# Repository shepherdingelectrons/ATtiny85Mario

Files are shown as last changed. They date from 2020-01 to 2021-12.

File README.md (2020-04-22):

# ATtiny85Mario

ATtiny85 Mario

Read about the software and hardware of ATtiny85Mario here:
https://shepherdingelectrons.blogspot.com/2020/01/tinymario.html

and the construction of a handset to play ATtiny85Mario in:

https://shepherdingelectrons.blogspot.com/2020/03/attiny-mario-handset.html

mario animation

Mario-style game with sound effects and music on twin OLED displays driven by ATtiny85 AVR. Having fun with the multiple challenges of working with small system constraints! :-)

**TinyMario**
Source code for Mario.  For music and sound effects to work, the EEPROM must be correctly burned first (see BurnEEPROM_ATtiny85 sketch)

- OLED code is derived from bitbang2's super fast code:
https://github.com/bitbank2/oled_turbo
- Mario theme music is taken from Mike Marburg's transcription of the score:
https://github.com/mikemalburg/arduino_annoyotrons_piezo/tree/master/annoy_piezo_mario_overworld
- Mario animation pixel art:
https://www.hackster.io/138689/pixel-art-on-oled-display-7f8697

**BurnEEPROM_ATtiny85**

Arduino sketch to compress the music and sound effects, then burn to ATTiny85 EEPROM

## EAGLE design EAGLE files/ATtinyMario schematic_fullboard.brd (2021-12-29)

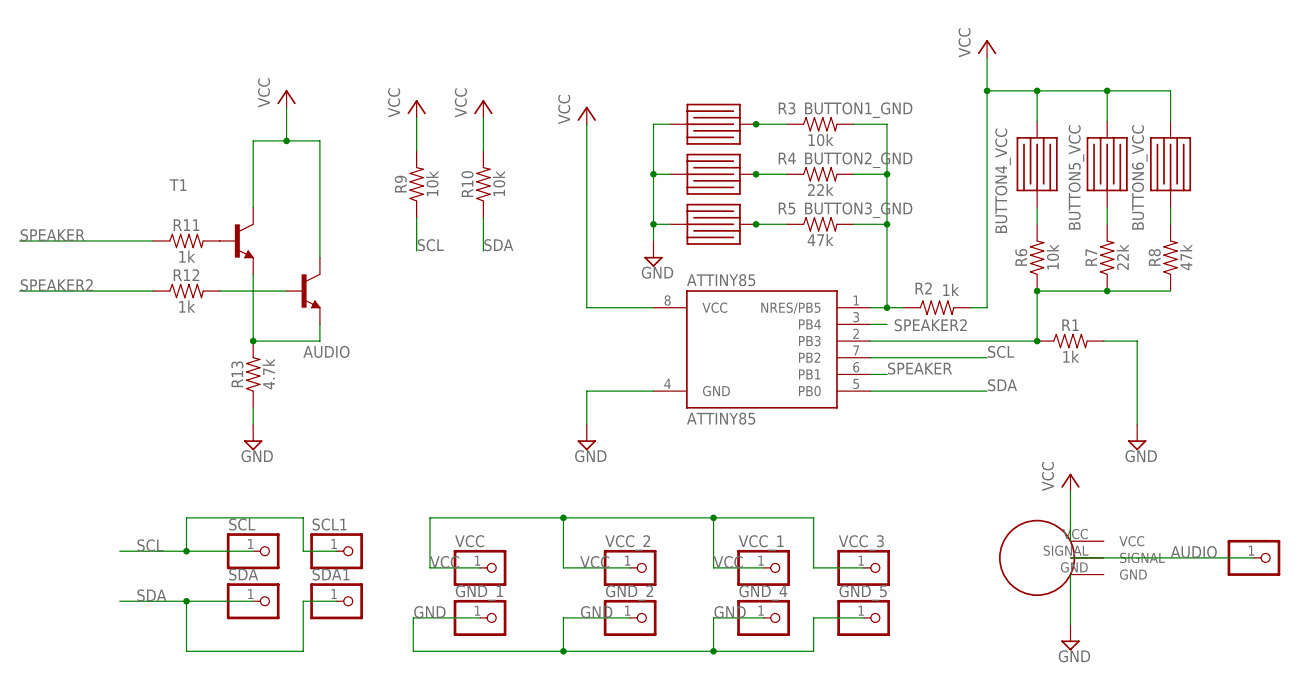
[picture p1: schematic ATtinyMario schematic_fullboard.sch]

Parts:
ATTINY85: ATTINY85; PDIP08_300MIL
GND_1, GND_2, GND_3, GND_4, GND_5: PINHD-1X1; 1X01
R1, R2, R11, R12: 1k; AXIAL-0.3
R3, R6, R9, R10: 10k; AXIAL-0.3
R4, R7: 22k; AXIAL-0.3
R5, R8: 47k; AXIAL-0.3
R13: 4.7k; AXIAL-0.3
SCL, SCL1: PINHD-1X1CB; 1X01-CLEANBIG
SDA, SDA1: PINHD-1X1CB; 1X01-CLEANBIG
T1, T2: 2N2222; TO92-EBC-OVAL
U$1, U$2, U$3, U$4, U$6, U$7: PCB_BUTTON_DEVICE; PCB_BUTTON
U$5: VOLUME_WHEEL; VOLUME_PCB
VCC: PINHD-1X1; 1X01
VCC_1, VCC_2, VCC_3: PINHD-1X1; 1X01

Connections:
AUDIO: GND_3.1, R13.P$2 (2), T1.E, T2.E, U$5.SIGNAL
BUTTON1_GND: R3.P$1 (1), U$1.PAD1
BUTTON2_GND: R4.P$1 (1), U$6.PAD1
BUTTON3_GND: R5.P$1 (1), U$7.PAD1
BUTTON4_VCC: R6.P$2 (2), U$2.PAD2
BUTTON5_VCC: R7.P$2 (2), U$3.PAD2
BUTTON6_VCC: R8.P$2 (2), U$4.PAD2
GND: ATTINY85.4 (GND), GND_1.1, GND_2.1, GND_4.1, GND_5.1, R1.P$2 (2), R13.P$1 (1), U$1.PAD2, U$5.GND, U$6.PAD2, U$7.PAD2
unnamed: ATTINY85.1 (NRES/PB5), R2.P$1 (1), R3.P$2 (2), R4.P$2 (2), R5.P$2 (2)
unnamed: ATTINY85.2 (PB3), R1.P$1 (1), R6.P$1 (1), R7.P$1 (1), R8.P$1 (1)
unnamed: R11.P$2 (2), T1.B
unnamed: R12.P$2 (2), T2.B
SCL: ATTINY85.7 (PB2), R9.P$1 (1), SCL.1, SCL1.1
SDA: ATTINY85.5 (PB0), R10.P$1 (1), SDA.1, SDA1.1
SPEAKER: ATTINY85.6 (PB1), R11.P$1 (1)
SPEAKER2: ATTINY85.3 (PB4), R12.P$1 (1)
VCC: ATTINY85.8 (VCC), R2.P$2 (2), R9.P$2 (2), R10.P$2 (2), T1.C, T2.C, U$2.PAD1, U$3.PAD1, U$4.PAD1, U$5.VCC, VCC.1, VCC_1.1, VCC_2.1, VCC_3.1

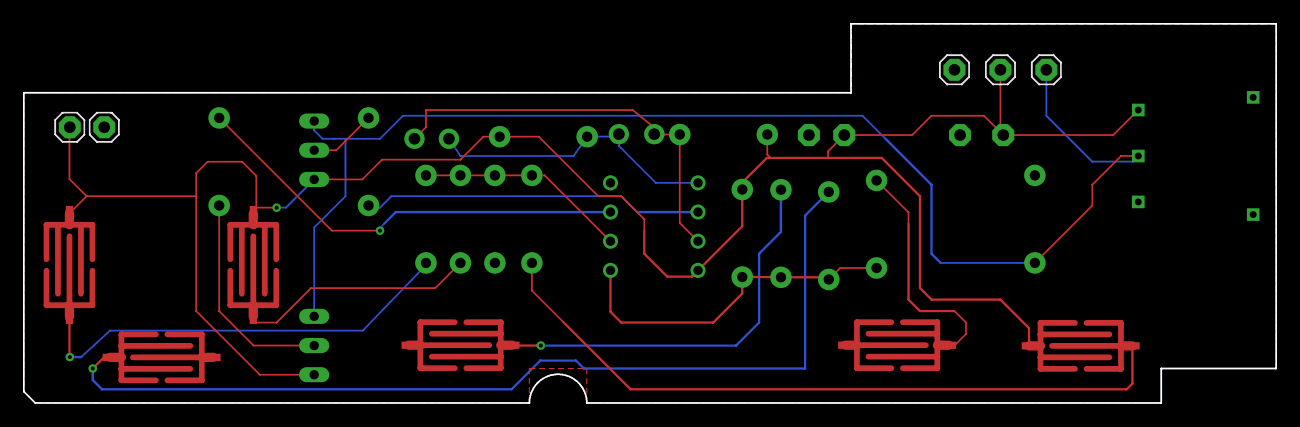
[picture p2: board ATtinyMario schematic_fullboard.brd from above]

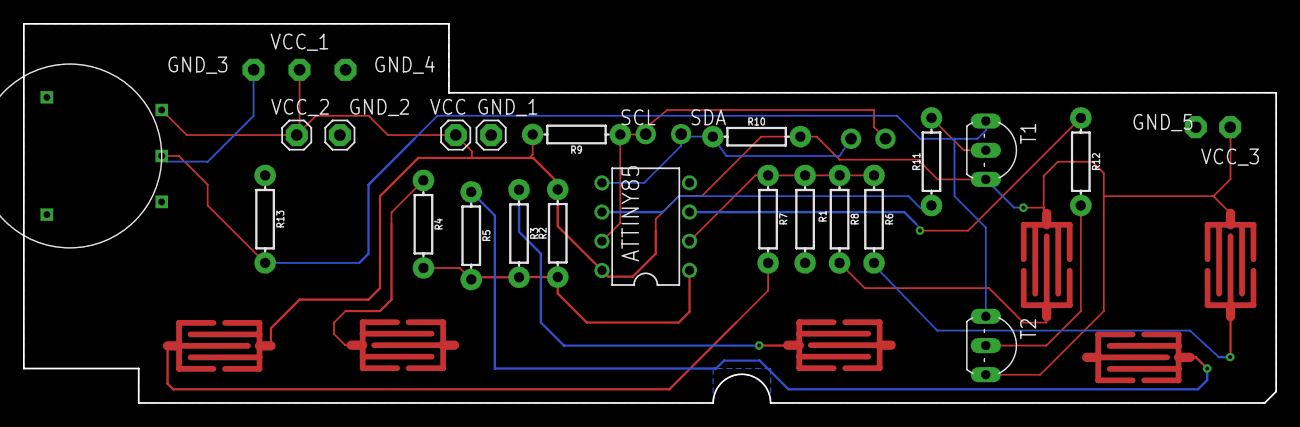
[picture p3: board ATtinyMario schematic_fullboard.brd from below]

Board: 2 copper layers, 109.0 x 33.0 mm, 36 parts (23 on the bottom side), 17 nets.

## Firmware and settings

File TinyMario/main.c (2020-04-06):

#define F_CPU 16000000L

#include <avr/io.h>
#include <avr/interrupt.h>
#include <avr/pgmspace.h>
#include <avr/eeprom.h>
#include "mario.h"
#include "mario_tiles.h"
#include "bricks.h"
#include "font_digits.h"
#include "oled_lib.h"

#define TEST_BUTTONS 1


struct music_table {
  uint16_t startpos;
  uint8_t len;
};

enum mario_state {idle, left, right, squash, dead};
enum mario_jumpstate {nojump, jumpup, jumpdown};
enum mario_direction {faceleft, faceright};
enum game_state {normal, paused, paused_ready, pause_return, mario_dying};

struct character {
  int16_t x, y;
  int16_t oldx[2], oldy[2];
  enum mario_state state;
  enum mario_jumpstate jumpstate;
  enum mario_direction dir;
  int8_t vx, vy;
  uint8_t frame;
  uint8_t collision;
  uint8_t coincollector;
  uint8_t mask;
  uint8_t w;
};

#define MAX_GOOMBAS 3

struct character mario, goomba[MAX_GOOMBAS], fireball;

struct toneController {
  uint8_t music_index, music_pos, music_note, noteordelay;
  uint16_t current_delay;
  uint8_t soundeffect; // 0 = Music, 1=Sound effect (affects play priority and loop behaviour)
};

struct toneController MusicController;
struct toneController SoundEffectController;

#define COIN_SOUND 6
#define JUMP_SOUND 7
#define HITHEAD_SOUND 8
#define PAUSE_SOUND 9

#define FIREBALL_SPEED 3

const uint8_t music_seq[] = {0, 1, 1, 2, 3, 2, 4, 2, 3, 2, 4, 5}; // 12 elements: 0-11. Go back to position 1 on overflow.

// soundeffect = 0: 1 passed onto myTone: Timer1 is used for Music - SPEAKER 
// soundeffect = 1: 0 passed onto myTone: Timer0 is used for sound effects - SPEAKER2

//#define SINGLE_SPEAKER // means we want to mix MUSIC and SOUND_EFFECTS in hardware (using SOUND_EFFECTS pin PB1), else have a pin for each

#define MUSIC_SPEAKER 4 // IC pin 3: PB4, Timer 1, OC1B - MUSIC (was speaker)
#define SOUNDEFFECT_SPEAKER 1// IC pin 6: PB1, Timer 0, OCOB - Sound effects (was speaker 2)

#define LEFT_OLED_ADDRESS 0x3C;
#define RIGHT_OLED_ADDRESS 0x3D; // swapped
#define OLED_CONTRAST 0xFF //0x7F

#define BUTTON_LEFT 4
#define BUTTON_A 2
#define BUTTON_RIGHT 1

#define BUTTON2_DOWN 1
#define BUTTON2_B 2
#define BUTTON2_SELECT 4

#define WORLD_MAX_LEN 63

#define ADC0 0
#define ADC1 1
#define ADC2 2
#define ADC3 3

#define TEMPO_DEFAULT 800
#define TEMPO_FAST 500

uint8_t screen[WORLD_MAX_LEN + 1], soundeffectplaying = 0;

uint16_t viewx = 0, old_viewx = 0, rviewx_trigger, MusicSpeed = TEMPO_DEFAULT, mario_acc_timer = 0;
int delta_viewx = 0;

volatile long mymicros=0,ISR_micro_period=0; 
volatile long tone_timer1_toggle_count=0, tone_timer0_toggle_count = 0;

uint8_t coinframe = 1, cointimer = 0, coincount = 0;
uint32_t curr_seed = 0;
enum game_state gamestate = normal;

void drawSprite(int16_t, int16_t, uint8_t, uint8_t, const unsigned char *, uint8_t);
void getWorld(uint16_t);
void drawScreen(void);
void playSoundEffect(uint8_t);
void initMusic(struct toneController *);
void handleMusic(struct toneController *);
void mytone(unsigned long, unsigned long, uint8_t);
void handlemap_collisions(struct character *);
void collidecoins(uint8_t, uint8_t, uint8_t);
uint8_t collideThings(int, int, int, int, int, int, uint8_t, uint8_t);
uint8_t collideMario(int, int, uint8_t, uint8_t);
uint8_t findcoiny(uint8_t);
void animate_character(struct character *);
void draw_mario(void);
void blank_character(uint8_t, struct character *);
void vblankout(int, int, uint8_t);
void readbuttons(void);
void drawCoin(int, uint8_t);
void updateDisplay(uint8_t);
void oledWriteInteger(uint8_t, uint8_t, uint8_t);
void setup(void);
uint16_t readADC(uint8_t);
uint8_t next_random(uint8_t);
void killGoomba(uint8_t g_id);
void spawnGoomba(uint16_t);

void setup() {
	//_delayms(50);
	oledInit(0x3c, 0, 0);
	oledFill(0);
	oledInit(0x3d, 0, 0);
	oledFill(0);

	//oledFill(0b00001111);

	mario.mask = 3; //fireball.mask = 3;
	mario.w = 2;//fireball.w = 2;
	
	for (uint8_t i=0;i<MAX_GOOMBAS;i++)
	{
		goomba[i].mask = 3;
		goomba[i].w = 2;
		goomba[i].state=dead;
	}
	
	mario.x = 5;
	mario.y = 0;
	mario.state = idle;
	mario.jumpstate = jumpdown;
	mario.vx = 0;
	mario.vy = 0;
	mario.frame = 0;
	mario.dir = faceright;
	mario.coincollector = 1;

	fireball.mask=1;
	fireball.w=1;
	fireball.state=dead;
	
	//analogReference(0); // 0 = Vcc as Aref (2 = 1.1v internal voltage reference)
	
	//pinMode(SPEAKER, OUTPUT);
	//pinMode(SPEAKER2, OUTPUT);

#ifdef SINGLE_SPEAKER
	DDRB |= (1 << SOUNDEFFECT_SPEAKER);
#else
	DDRB |= (1 << MUSIC_SPEAKER); // OUTPUT
	DDRB |= (1 << SOUNDEFFECT_SPEAKER); // OUTPUT
#endif
	// Setup screen
	getWorld(0); //WORLD_MAX_LEN + 1); //,16);
	getWorld(16);
	getWorld(32);
	getWorld(48);

	rviewx_trigger = 24;//12;// if viewx > trigger*8 getWorld element in certain position.
	//drawScreen();

	MusicController.soundeffect = 0;
	SoundEffectController.soundeffect = 1;
	soundeffectplaying = 0;
	initMusic(&MusicController);

	// Change music speaker to a hardware pin that Timer1 supports - i.e. pin4 = PB4
	TCCR0A = 0;//notone0A();
	TIMSK = 0;

	TCCR1 = 0 ;
	GTCCR = 0;
	TIFR = 0;
	
	//goomba.x = 100; goomba.y = 0;
	//goomba.vx = 1; goomba.state=dead;

}


int main(void)
{
	static long loop_micros=0;
	
	setup();
	
	sei();
	
	while (1)
	{
		readbuttons();

		if (gamestate == normal)
		{
			handlemap_collisions(&mario); // Check for collisions with Mario and the world
			
			if (fireball.state!=dead)
			{
				handlemap_collisions(&fireball);
				if (fireball.y<0 || fireball.y>=63) {fireball.frame=90;fireball.y=0;fireball.vy=0;} 
				
				// 1 = UP, 2=RIGHT, 4=DOWN, 8=LEFT
				if (fireball.collision &1) fireball.vy=FIREBALL_SPEED;
				if (fireball.collision &4) fireball.vy=-FIREBALL_SPEED;
				if (fireball.collision &2) fireball.vx=-FIREBALL_SPEED;
				if (fireball.collision &8) fireball.vx=FIREBALL_SPEED;

				if (fireball.collision!=0) fireball.frame+=30;

				fireball.frame++;
				if (fireball.frame>100) fireball.state=dead;
			}

			animate_character(&mario); // just applies gravity, could be done elsewhere (i.e. handlemap_collisions physics?)
			
			for (uint8_t g=0;g<MAX_GOOMBAS;g++)
			{
				if (goomba[g].state!=dead) // Not dead. Alive you might say.
				{
					handlemap_collisions(&goomba[g]);
					animate_character(&goomba[g]);
				
					if (goomba[g].collision & 2) goomba[g].vx = -1;
					else if (goomba[g].collision & 8) goomba[g].vx = 1;

					if (goomba[g].x <= 0) {
						goomba[g].x = 0;
						goomba[g].vx = 1;
					}						// rviewx_trigger+40 is the *next* screen to write (i.e. doesn't exist yet), so turn around goomba if near edge
					if ((goomba[g].x>>3) >= rviewx_trigger+38) goomba[g].vx=-1; // if goomba attempst to walk off the edge of the known universe
					goomba[g].frame++;
					if (goomba[g].state==idle && goomba[g].frame >= 10) goomba[g].frame = 0;
					if (goomba[g].state==squash && goomba[g].frame>200) goomba[g].state=dead;
				} // end enemy not dead
				
				if (goomba[g].state==idle)
				{
					if (collideMario(goomba[g].x, goomba[g].y, 16, 16))
					{
						if (mario.vy > 0 && mario.jumpstate==jumpdown) {killGoomba(g);mario.vy = -7;mario.jumpstate = jumpup;playSoundEffect(JUMP_SOUND);}
						else playSoundEffect(HITHEAD_SOUND);
					}
					if (fireball.state==idle && collideThings(goomba[g].x, goomba[g].y, 16,16,fireball.x, fireball.y,8,8)) killGoomba(g);
					if (goomba[g].x<((int16_t)viewx-40)) killGoomba(g);
				}
			} // end goomba loop
			
			
			
			if (mario.frame++ >= 6) mario.frame = 0;

			cointimer++;  // Animate coin
			if (cointimer >= 5)
			{
				cointimer = 0;
				coinframe++;
				if (coinframe >= 5) coinframe = 1;
			}

			if (coincount >= 10 && coincount < 20) MusicSpeed = TEMPO_FAST; else MusicSpeed = TEMPO_DEFAULT;

			if (mario.x <= 192) viewx = 0;
			else if (viewx < mario.x - 192) viewx = mario.x - 192; // Do we need to change the viewport coordinate?

			uint16_t blockx = viewx >> 3; // viewx / 8;
			if (blockx >= rviewx_trigger) // convert viewx to blocks
			{
				getWorld(rviewx_trigger + 40);

				rviewx_trigger += 16;
			}

		} // gamestate == normal

		updateDisplay(0); // Draw screen
		oledWriteInteger(10, 0, coincount);
		
		drawCoin(0, 0);
		updateDisplay(1);
		
		// 1E6 / fps
		
		if (gamestate == normal) handleMusic(&MusicController);
		handleMusic(&SoundEffectController);
	
		while (mymicros-loop_micros<=25000) // 40 fps
		{
			if (gamestate == normal) handleMusic(&MusicController);
			handleMusic(&SoundEffectController);
		}
		loop_micros = mymicros;
		
	}

}

uint8_t next_random(uint8_t range)
{
	curr_seed = (curr_seed*1664525 + 1013904223) % 65536;
	return (uint8_t) (curr_seed % range);
}

uint16_t readADC(uint8_t adcpin)
{
	uint16_t value=0;
	
	for (uint8_t i=0;i<16;i++)
	{
	ADCSRA &=~(1<<ADEN); // disable ADC Enable, to be safe
	
	//while (ADCSRA & (1<<ADSC)); // wait for ADSC bit to clear
	
	ADMUX = (adcpin & 7) << (MUX0); // REF bits are zero = Vcc as voltage reference
	// ref = 0 : Vcc as voltage reference
	// ref = (1<<REFS1) : 1.1 V internal as reference
	ADCSRA = (1<<ADEN) | (1<<ADPS2) | (1<<ADPS1) | (1<<ADPS0);// divide by 16 | (1<<ADPS1);// | (1<<ADPS0); // Enable ADC in general
	
	ADCSRA |= (1<<ADSC); // Start ADC conversion
	while(ADCSRA & (1<<ADSC)); // ADSC goes to zero when finished
	//while(!(ADCSRA & (1<<ADIF)));
	value+=ADC;
	}
	return value>>4; // divide by eight, average
}

void drawSprite(int16_t x, int16_t y, uint8_t w, uint8_t h, const unsigned char *buf, uint8_t flip)
{
  // Do clipping:
  //if (x<0) x=0

  // Assume don't need clipping for now
  //ssd1306_send_command3(renderingFrame | (y >> 3), 0x10 | ((x & 0xf0) >> 4), x & 0x0f);
  //uint8_t offset_y = y & 0x07;

  int16_t sx, sy;
  unsigned char *pos = (unsigned char*)buf;
  uint8_t start_height=0, stop_height=h/8, xoff = 0, xw = w;
  // i.e. for write_higeht 16 means 2 lots of 8 bits.

  if (x >= 128 || x <= -w) return;
  if (y>63) return;
  if (x < 0) {
    xoff = -x;
    x = 0;
  }
  if (x + w > 128) xw = 128 - x;

  uint8_t temp[16];
  
  if (y<0)
  {
	start_height=1+((-y)>>3); // i.e. -7 to -1 (inclusive): start_height = 1
	y=0;
  }
  
  if (y+h>64) stop_height = 8-(y>>3);
	
  for (uint8_t j = start_height; j < stop_height; j++) // goes from 0 to 1 (across y-axis)
  {
    sx = x ;
    sy = y + (j-start_height) * 8;

    // SetCursor
    //ssd1306_send_command3(renderingFrame | (sy >> 3), 0x10 | ((sx & 0xf0) >> 4), sx & 0x0f);
    oledSetPosition(sx, sy);

    //ssd1306_send_data_start();

    // Copy into local buffer forwards or backwards, then pass on :)

    for (uint8_t i = xoff; i < xw; i++) // i.e. i goes 0 to 15 (across x axis) if not clipped
    {
      if (flip == 0) pos = (unsigned char*)buf + j + (i * (h>>3));
      else pos = (unsigned char*)buf + j + ((w - 1 - i) * (h>>3)); // h/8
      temp[i - xoff] =  pgm_read_byte(pos);
    }

    // cursor is incremented auto-magically to the right (x++) per write
    
    oledWriteDataBlock(temp, xw - xoff); 
    
  }
}

void killGoomba(uint8_t g_id)
{
	goomba[g_id].state = squash;
	goomba[g_id].frame=17;
	goomba[g_id].vx=0;
	goomba[g_id].x++;//.x++ forces a blank replot
}
void spawnGoomba(uint16_t pos)
{	// Check here for goomba availability
	for (uint8_t g=0;g<MAX_GOOMBAS;g++)
	{
		if (goomba[g].state==dead)
		{
			goomba[g].x = (pos<<3);
			goomba[g].y = 0;
			goomba[g].vx = 1;
			goomba[g].vy = 0;
			goomba[g].frame = 0;
			goomba[g].state=idle;
			return;
		}	
	}
}

// getWorld function is inspired by the "Map::GenerateRoom" function in the Squario project on the Arduboy, found here:
// https://github.com/arduboychris/Squario/blob/master/SquarioGame.cpp

void getWorld(uint16_t vx)
{
  // vx is in units of bricks (i.e. vx/8), one screen is 16 wide
  
  uint8_t floor, gap=0;
  uint8_t cx = (vx & 63);
  
  floor = 5 + next_random(3);  // can be 5, 6 or 7

  for (uint8_t i=cx; i<cx+16;i++)
  {
	screen[i]=0;
	
	if (!next_random(5)) screen[i]=1; // Spawn a coin
	
	if (!gap)
	{
		//SetColumn(ifloor,7);
		for (uint8_t f=floor;f<=7;f++)
			screen[i] |= (1<<f);
		if (!next_random(10)) // 1 in 10 chance of setting a gap
		{
			gap = 2 + next_random(4); // 2-5 
			if (vx==0) gap=0; // no gaps on first screen
		}
		else if (!next_random(5) && vx!=0) // change floor height
		{
			if (!next_random(2) && floor<7) floor++;
			else if (floor>1) floor--;
		}
		if (!next_random(16)) spawnGoomba((uint16_t)vx+8);// spawn half way across screen so there are no boundary issues on the right
	} 
	else gap--;
  }

}

void drawScreen()
{
  uint8_t starti, stopi, wrapped_i=0, coin = 0, pipe = 0;
  int xoffset;

  starti = (viewx >> 3) & WORLD_MAX_LEN;  // wrap round (could be WORLD_BUFFER - 1)
  xoffset = -(viewx & 0x07);
  stopi = starti + 16;

  if (starti > 0) {
    starti--;  // Handles blanking blacking out edge when *just* disappeared off screen
    xoffset -= 8;
  }

  if (xoffset != 0) stopi++; // Need to add an extra brick on the right because we are not drawing left brick fully
  
  for (uint8_t i = starti; i < stopi; i++) // limit of 256
  {
    if (delta_viewx < 0) wrapped_i = (i + 1) & WORLD_MAX_LEN; // wrap round (could be WORLD_BUFFER - 1)
    else if (delta_viewx > 0) wrapped_i = (i - 1) & WORLD_MAX_LEN;

    coin = 0;
    if (screen[i & WORLD_MAX_LEN] & (1 << 0)) coin = 1;

    for (uint8_t y = 1; y < 8; y++)
    {
      if (screen[i & WORLD_MAX_LEN] & (1 << y)) // There is a block here
      {
        if (delta_viewx < 0) // screen is scrolling right and we are within array limit
          if (!(screen[wrapped_i] & (1 << y))) vblankout(xoffset + 8, y << 3, -delta_viewx); // View moving to the right, blocks scrolling to the left,
        // therefore blank out smearing trail to the right of block
        // but only if there isn't a block there.
        if (delta_viewx > 0)
          if (!(screen[wrapped_i] & (1 << y))) vblankout(xoffset - delta_viewx, y << 3, delta_viewx);

        if ((y == 5 || y == 6) && pipe != 0) // it's a pipe column
        {
          if (y == 5 && pipe == 2) drawSprite(xoffset - 8, y << 3, 16, 16, &mario_pipe2[0], 0);
          //drawSprite(xoffset, y<<3,8,8,&block8x8[0], 0);
        }
        else
        { // don't draw bricks on pipes
          //if (y == 7) drawSprite(xoffset, y << 3, 8, 8, &block8x8[0], 0);
          //else 
		  if ((screen[i & WORLD_MAX_LEN] & (1 << (y - 1))) == 0) // y>0 and nothing above, draw grassy brick
            drawSprite(xoffset, y << 3, 8, 8, &topbrick[0], 0);
          else drawSprite(xoffset, y << 3, 8, 8, &brick8x8[0], 0); // else brick is default
        }

        if (coin)
        {
          if (y == 1) drawCoin(xoffset, (y - 1) << 3);
          else drawCoin(xoffset, (y - 2) << 3);
          coin = 0;
        }
      }
      //else vblankout(xoffset,y<<3,8);
    }
    xoffset += 8;
  }
}

void playSoundEffect(uint8_t num)
{
  if (soundeffectplaying) return; // only one at once
  // 6 - coin collect sound

  tone_timer0_toggle_count = 0; // stop current sound

  SoundEffectController.music_pos = 0;
  SoundEffectController.music_index = num;
  SoundEffectController.noteordelay = 1;

  soundeffectplaying = 1;
}

void initMusic(struct toneController *controller)
{
  controller->music_pos = 0; // First position in music sequence, i.e. 0,1,2,3 etc )
  controller->music_index = music_seq[controller->music_pos];//pgm_read_byte(&music_seq[0]+music_pos); // melody 0 (=intro
  controller->music_note = 0; // First note of music_index melody
  controller->noteordelay = 1; //simulate end of a delay to start the note
}

void handleMusic(struct toneController *controller)//, uint8_t channel_id)
{
  uint16_t *melody;
  uint8_t numNotes;
  uint8_t *entry_pos;
  
  // soundeffect = 1: Timer0 is used for music - SPEAKER2
  // soundeffect = 0: Timer1 is used for sound effects - SPEAKER 

  if ((controller->soundeffect == 0 && tone_timer1_toggle_count == 0) || (controller->soundeffect == 1 && tone_timer0_toggle_count == 0 && soundeffectplaying == 1))
  {
    if (controller->noteordelay == 0) // 0 = NOTE just ended, therefore now delay
    {
      // Note ended, start a delay
      controller->current_delay = (controller->current_delay/3);

      if (controller->soundeffect == 0) mytone(0, controller->current_delay,1);
	  else mytone(0, controller->current_delay,0);

      // Advance to next note position
      controller->music_note++;								// sizeof(music_table)
      numNotes = eeprom_read_byte((uint8_t *)(controller->music_index * 3) + 2); // next position is numNotes

      if (controller->music_note >= numNotes) // exceeded notes in this melody part
      {
        controller->music_note = 0;
        controller->music_pos++; // advance sequence position

        if (controller->soundeffect == 1) // we are in the sound effect handler
        {
          soundeffectplaying = 0; // Global, control is passed back onto music handler, music will restart at next tone.
        }
        else if (controller->music_pos >= 12) // In music handler, and sequence has overflowed.
        {
          controller->music_pos = 1; // We are in the music handler
        }
        controller->music_index = music_seq[controller->music_pos];//pgm_read_byte(&music_seq[0]+music_pos);
      }
      controller->noteordelay = 1; //delay is next
    } // end note ended
    else if (controller->noteordelay == 1) // 1 = DELAY
    {
      // Delay ended, play next note
      entry_pos = (uint8_t *)(controller->music_index * 3);//sizeof(music_table);
      melody = (uint16_t *)eeprom_read_word((uint16_t*)entry_pos); // EEPROM position in entry table
      entry_pos += 2;

      //numNotes = eeprom_read_byte(entry_pos); // next position is numNotes
      //noteDurations = (uint8_t*)(melody + (numNotes)); // noteDurations follows the melody in EEPROM

      uint16_t ms = 1000, freq;

      if (controller->soundeffect == 0) ms = MusicSpeed; // Music speed might change

      freq = eeprom_read_word(melody + controller->music_note);  // duration is now encoded into top 3 bits of frequency.
	  uint8_t note;
	  note = freq >> 13;// Extract 2,4,8,16th,32nd note etc from freq
	  freq &= 0x1FFF;
	  controller->current_delay = ms>>note; // shift rather than divide.
	  
      if (controller->soundeffect == 0) mytone(freq, controller->current_delay,1);
      else mytone(freq, controller->current_delay,0); // Sound effects
     
      controller->noteordelay = 0;
    }// end delay ended
  } // wnd time delay lapsed
}

void mytone(unsigned long frequency, unsigned long duration, uint8_t timer) // Hard coded for pin PB1 (OCR0A)
{
  uint32_t ocr;
  uint8_t prescalarbits = 0b001;
  uint8_t output = 1;

// soundeffect = 0: 1 passed onto myTone: Timer1 is used for Music - SPEAKER
// soundeffect = 1: 0 passed onto myTone: Timer0 is used for sound effects - SPEAKER2

  // timer = 0 - use timer 0 and SPEAKER2 pin
  // timer = 1 - use timer 1 and SPEAKER pin
  
  // Try music on PB1, using OC1A (rather than OC1B on PB4)

  if (frequency == 0)
  { // Means we want to switch off the pin and do a pause, but not output to the hardware pin
    output = 0; frequency = 300; // A dummy frequency - timings are calculated but no pin output.
  }

  ocr = F_CPU / (2 * frequency);
  
  if (timer==0)
  {
    if (ocr > 256)
    {
      ocr >>= 3; //divide by 8
      prescalarbits = 0b010;  // ck/8
      if (ocr > 256)
      {
        ocr >>= 3; //divide by a further 8
        prescalarbits = 0b011; //ck/64
        if (ocr > 256)
        {
          ocr >>= 2; //divide by a further 4
          prescalarbits = 0b100; //ck/256
          if (ocr > 256)
          {
            // can't do any better than /1024
            ocr >>= 2; //divide by a further 4
            prescalarbits = 0b101; //ck/1024
          } // ck/1024
        }// ck/256
      }// ck/64
    }//ck/8*/
  } //timer==0
  else
  {
    prescalarbits = 1;
    while (ocr > 0xff && prescalarbits < 15) {
          prescalarbits++;
          ocr>>=1;
    }
  }
   
  ocr -= 1;

  if (timer==0)
  {
    tone_timer0_toggle_count = (2 * frequency * duration) / 1000;
  }
  else
  {
    // timer1 scalar code here
    tone_timer1_toggle_count = (2 * frequency * duration) / 1000;
    // Music uses timer1 and is on continuously so use as a crude timer
    ISR_micro_period = 500000L / frequency; // 1E6 / (2*frequency), because ISR is called 2 times every period.
  }

  if (output)
  {
    if (timer==0)
    {
    TCCR0A = (1 << COM0B0) | (1 << WGM01); // = CTC // Fast PWM | (1<<WGM01) | (1<<WGM00);
    }
    else 
    {
	#ifndef SINGLE_SPEAKER
		GTCCR = (1 << COM1B0); // set the OC1B to toggle on match
	#endif
    }
  }
  else // no output 
  {
    if (timer==0)
    {
      TCCR0A |= (1 << WGM01); // I guess this is always true
      TCCR0A &= ~(1 << COM0B0); // No hardware pin output 
	  #ifndef SINGLE_SPEAKER
		PORTB &= ~(1 << SOUNDEFFECT_SPEAKER); // Set pin LOW
	  #endif
    }
    else
    {
      // timer 1 code to turn off hardware support here
	  #ifdef SINGLE_SPEAKER
		  TCCR1 &= (1 <<COM1A0);  // disconnect OC1A
	  #else 
		  GTCCR &= (1 <<COM1B0); // disconnect hardware pin
		  PORTB &= ~(1 << MUSIC_SPEAKER); // Set pin LOW
	  #endif
    }
  }

  if (timer==0)
  {
    TCCR0B = prescalarbits << CS00; //(1<<CS01);// | (1<<CS00); // Scalar. //prescalarbits;//
    TCNT0 = 0; // Set timer0 counter to 0
    OCR0A = ocr; // set compare value
    TIMSK |= (1 << OCIE0A); // Activate timer0 COMPA ISR
  }
  else
  {
    TCCR1 = (1<<CTC1)| (prescalarbits<<CS10); // CTC1 : Clear Timer/Counter on Compare Match, after compare match with OCR1C value
	#ifdef SINGLE_SPEAKER
		if (output) TCCR1 |= (1<<COM1A0);
	#endif
    TCNT1 = 0; // timer 1 counter = 0
    OCR1C = ocr; // set compare value 
	#ifdef SINGLE_SPEAKER
		TIMSK |= (1 << OCIE1A); // Activate timer1 COMPA ISR
	#else
		TIMSK |= (1 << OCIE1B); // Activate timer1 COMPB ISR
	#endif
  }
  
}
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

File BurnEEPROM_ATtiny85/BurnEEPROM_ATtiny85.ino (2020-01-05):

#include <avr\eeprom.h>
#include "music_notes.h"
#include "mario_theme.h"

struct melody{
  uint16_t* melody; //+ 0
  uint8_t* noteDurations; // +2
  uint8_t numNotes; // +3
  uint8_t progmem; // + 4
};

struct music_table{
uint16_t startpos;
uint8_t len;
};

#define NUM_ENTRIES 10

struct music_table music_entries[NUM_ENTRIES];

const struct melody theme_music[]={{Melody_Intro, NoteDurations_Intro, sizeof(Melody_Intro)>>1,1},    // 0
                            {Melody_Refrain, NoteDurations_Refrain, sizeof(Melody_Refrain)>>1,1}, // 1
                            {Melody_Part2_1, NoteDurations_Part2_1, sizeof(Melody_Part2_1)>>1,0}, // 2
                            {Melody_Part2_2, NoteDurations_Part2_2, sizeof(Melody_Part2_2)>>1,0}, // 3
                            {Melody_Part2_3, NoteDurations_Part2_3, sizeof(Melody_Part2_3)>>1,0}, // 4
                            {Melody_Part3_1, NoteDurations_Part3_1, sizeof(Melody_Part3_1)>>1,1}, // 5
                            {CoinSound, CoinSound_Durations,sizeof(CoinSound)>>1,0}, // 6 - Coin sound effect
                            {JumpSound, JumpSound_Durations,sizeof(JumpSound)>>1,1},// 7 - Jump sound effect
                            {HitHeadSound, HitHead_Durations,sizeof(HitHeadSound)>>1,1},// 8 - Hit head sound effect
                            {PauseSound, PauseSound_Durations,sizeof(PauseSound)>>1,0}// 9 - Pause sound effect
                            };

uint8_t *pos;
uint8_t buffer_P[100];

// Play back variables:
struct toneController{
  uint8_t music_index=0, music_pos=0, music_note=0,noteordelay=0;    
  uint16_t current_delay=0;
  uint8_t soundeffect; // 0 = Music, 1=Sound effect (affects play priority and loop behaviour)
};

struct toneController MusicController;

const uint8_t music_seq[] ={0,1,1,2,3,2,4,2,3,2,4,5}; // 12 elements: 0-11. Go back to position 1 on overflow.

#define SPEAKER 4//3 //4 // Can use hardware Timer1 OC1B

extern volatile uint8_t *tone_timer_pin_register;
extern volatile long tone_timer_toggle_count;
uint8_t dummy_register;

///////////////////////////////////////////// end playback variables

  
void setup() {
  // put your setup code here, to run once:
  burnEEPROM();
  DDRB|=(1<<SPEAKER); // OUTPUT
  
  MusicController.soundeffect=0;
  initMusic(&MusicController);
}

void initMusic(struct toneController *controller)
{
     controller->music_pos=0; // First position in music sequence, i.e. 0,1,2,3 etc )
     controller->music_index = music_seq[controller->music_pos];//pgm_read_byte(&music_seq[0]+music_pos); // melody 0 (=intro
     controller->music_note = 0; // First note of music_index melody     
     controller->noteordelay=1; //simulate end of a delay to start the note
}

uint8_t* burnmusic(uint8_t entry)
{
  uint16_t *melody;
  uint8_t *noteDurations;
  uint8_t progmem, len;

  uint8_t duration,power;
  
  // Extract the good stuff
  melody = theme_music[entry].melody;
  noteDurations = theme_music[entry].noteDurations;
  progmem = theme_music[entry].progmem;
  len = theme_music[entry].numNotes;
  
  // Sort the table entry out
  music_entries[entry].len = len;
  music_entries[entry].startpos = pos;
  eeprom_write_block(&music_entries[entry],entry*sizeof(music_table),sizeof(music_table));
  
  // Write notes in next pos
  if (progmem)
  {
    memcpy_P(&buffer_P[0],melody,len*2);
  }
  else
  {
    memcpy(&buffer_P[0], melody,len*2);
  }

  // melody in buffer_P
  
  for (uint8_t i=0;i<len;i++)
    { 
      if (progmem) duration = pgm_read_byte(noteDurations+i);
      else duration = noteDurations[i];
      
      power = 1;
      if (duration==2) power = 1;
      else if (duration==4) power=2;
      else if (duration==8) power=3;
      else if (duration==16) power=4;
      else if (duration==32) power=5;
      else if (duration==64) power=6;
      else if (duration==128) power=7;

      buffer_P[1+(i*2)] |= (power<<5); // bytes are swapped in uint16_t
    }
  eeprom_write_block(buffer_P, pos, len*2); // 2 bytes per note  
  pos+=(len*2);

  /*
  // Write durations to EEPROM
  if (progmem)
  {
    memcpy_P(&buffer_P[0],noteDurations,len);
    eeprom_write_block(buffer_P, pos, len);
  }
  else
  {
    eeprom_write_block(noteDurations, pos, len); // 2 bytes per note
  }
  pos+=(len);*/
}

void burnEEPROM(void)
{
   pos=(NUM_ENTRIES*sizeof(music_table)); // Leave room for entry table at start

   for (uint8_t i=0;i<NUM_ENTRIES;i++)
      burnmusic(i); 

  // for (uint16_t i=0; i<512;i++)
//    eeprom_write_byte(i,0xFF);
   
  // burnmusic(0);
}


void loop() {
  // put your main code here, to run repeatedly:
  handleMusic(&MusicController);
}


void handleMusic(struct toneController *controller)
{  
  uint16_t *melody;
  uint8_t *noteDurations;
  uint8_t numNotes;
  uint8_t *entry_pos;

  if ((controller->soundeffect==0 && tone_timer_toggle_count==0))
  {    
    if (controller->noteordelay==0) // 0 = NOTE just ended, therefore now delay
    {
      // Note ended, start a delay
      controller->current_delay = (controller->current_delay * 0.30f); 
      
      if (controller->soundeffect==0) // Music
      {  
      tone(SPEAKER, 100, controller->current_delay); // do a low tone instead of using millis and switch off the pin!

      tone_timer_pin_register = &dummy_register; // don't do software toggle of the pin :)
      PORTB&=~(1<<SPEAKER);
      }
      
      // Advance to next note position
      controller->music_note++;           
      entry_pos = controller->music_index*sizeof(music_table);
      entry_pos+=2;
      numNotes = eeprom_read_byte(entry_pos); // next position is numNotes
      
      if (controller->music_note>=numNotes) //theme_music[controller->music_index].numNotes) // exceeded notes in this melody part
      {
        controller->music_note=0;
        controller->music_pos++; // advance sequence position

        if (controller->soundeffect==0 && controller->music_pos>=12) // In music handler, and sequence has overflowed.
        {
          controller->music_pos=1; // We are in the music handler
        }  
        controller->music_index = music_seq[controller->music_pos];//pgm_read_byte(&music_seq[0]+music_pos);
      
      }
      controller->noteordelay=1; //delay is next
    } // end note ended
   else if (controller->noteordelay==1) // 1 = DELAY
    {
     // Delay ended, play next note
     
     entry_pos = controller->music_index*sizeof(music_table);
     melody = eeprom_read_word((uint16_t*)entry_pos); // EEPROM position in entry table
     entry_pos+=2;
     numNotes = eeprom_read_byte(entry_pos); // next position is numNotes
     //noteDurations = (uint8_t*)(melody +(numNotes));//melody + (uint16_t)numNotes; // noteDurations follows the melody in EEPROM
    
     uint16_t ms=1000,freq;

     freq = eeprom_read_word(melody+controller->music_note);
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

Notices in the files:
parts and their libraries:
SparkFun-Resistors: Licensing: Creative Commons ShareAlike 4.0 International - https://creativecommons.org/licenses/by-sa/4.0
